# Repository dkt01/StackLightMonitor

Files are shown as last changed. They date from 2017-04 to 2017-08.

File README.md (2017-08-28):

# StackLightMonitor

Documentation Status (https://codedocs.xyz/dkt01/StackLightMonitor/)

[hackaday.io Project Page](https://hackaday.io/project/26995-stack-light-monitor)

[Demo Video](https://youtu.be/2Hm4lpO7gss)
Demo video

Jenkins monitor using industrial stack light as output

## Software Dependencies

The following packages are necessary to run this software:

+ [EtherCard](https://github.com/jcw/ethercard): Driver for ENC28J60 Ethernet controller on Arduino microcontrollers
+ [SparkFun Arduino_Boards](https://github.com/sparkfun/Arduino_Boards): Support for Arduino Pro Micro in Arduino IDE
+ [HTMLMinifier](https://github.com/kangax/html-minifier): HTML and Javascript minifier to reduce html page size.
+ [ImageMagick](http://www.imagemagick.org/script/index.php): Image conversion tool to create favicon.ico file from svg source.

## Attribution

Favicon is a derivative of ["Database" by Tinashe Mugayi](https://thenounproject.com/search/?q=database&creator=1554334&i=955064).  It is covered by the [Creative Commons 3.0 Attribution License](https://creativecommons.org/licenses/by/3.0/us/).

Config page uses CSS from [Pure CSS](https://purecss.io).  It is covered by the [Yahoo! BSD License](https://github.com/yahoo/pure-site/blob/master/LICENSE.md).

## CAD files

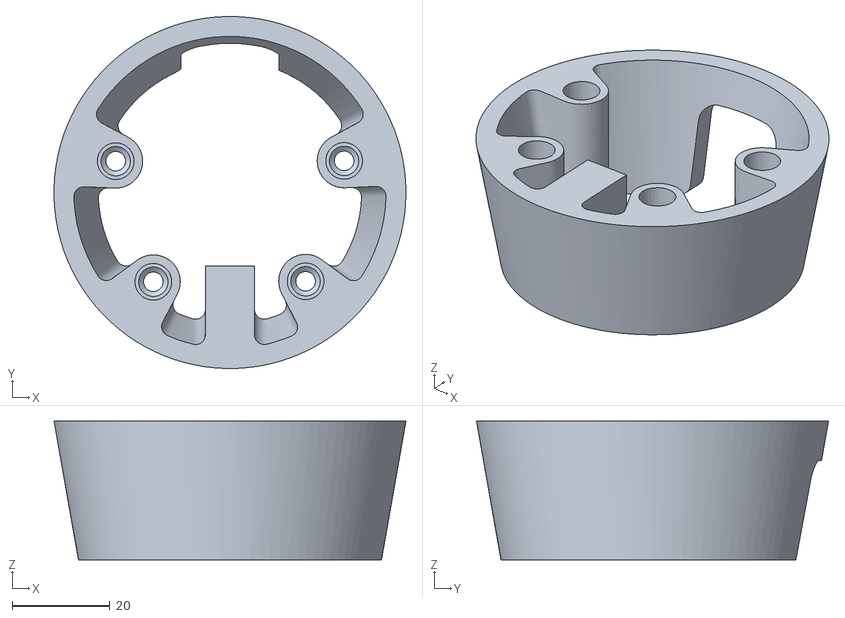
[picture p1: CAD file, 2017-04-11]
CAD/baseBottom.stl
71.8 x 71.9 x 28.3

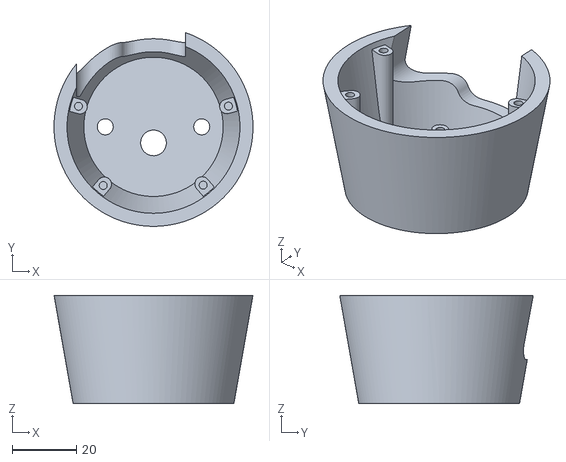
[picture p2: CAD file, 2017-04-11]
CAD/baseTop.stl
61.9 x 60.2 x 33.7

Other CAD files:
CAD/97.ipt
CAD/Arduino Pro Micro Sparkfun.ipt
CAD/ArduinoProMicro.iam
CAD/ElectricalAssembly.iam
CAD/Ethernet.iam
CAD/Ethernet.ipt
CAD/FemaleHeader-01.iam
CAD/FemaleHeader-01.ipt
CAD/FemaleHeader-02.iam
CAD/FemaleHeader-02.ipt
CAD/FemaleHeader.iam
CAD/FemaleHeader.ipt
CAD/FemaleHeader_Single-01.iam
CAD/FemaleHeader_Single-02.iam
CAD/FemaleHeader_Single.iam
CAD/FemalePin-01.ipt
CAD/FemalePin-02.ipt
CAD/FemalePin.ipt
CAD/FullAssembly.iam
CAD/KLDHCX-0202-B_rA2.ipt
CAD/LM317.ipt
CAD/MaleHeader-01.iam
CAD/MaleHeader-01.ipt
CAD/MaleHeader-02.iam
CAD/MaleHeader-02.ipt
CAD/MaleHeader.iam
CAD/MaleHeader.ipt
CAD/PCB.ipt
CAD/Screw Terminal Block 5mm.ipt
CAD/Shield.iam
CAD/TO-92.ipt
CAD/baseBottom.ipt
CAD/baseTop.ipt
CAD/stackLight.iam
CAD/stackLightBase.ipt
CAD/stackLightElement.ipt
CAD/stackLightTop.ipt

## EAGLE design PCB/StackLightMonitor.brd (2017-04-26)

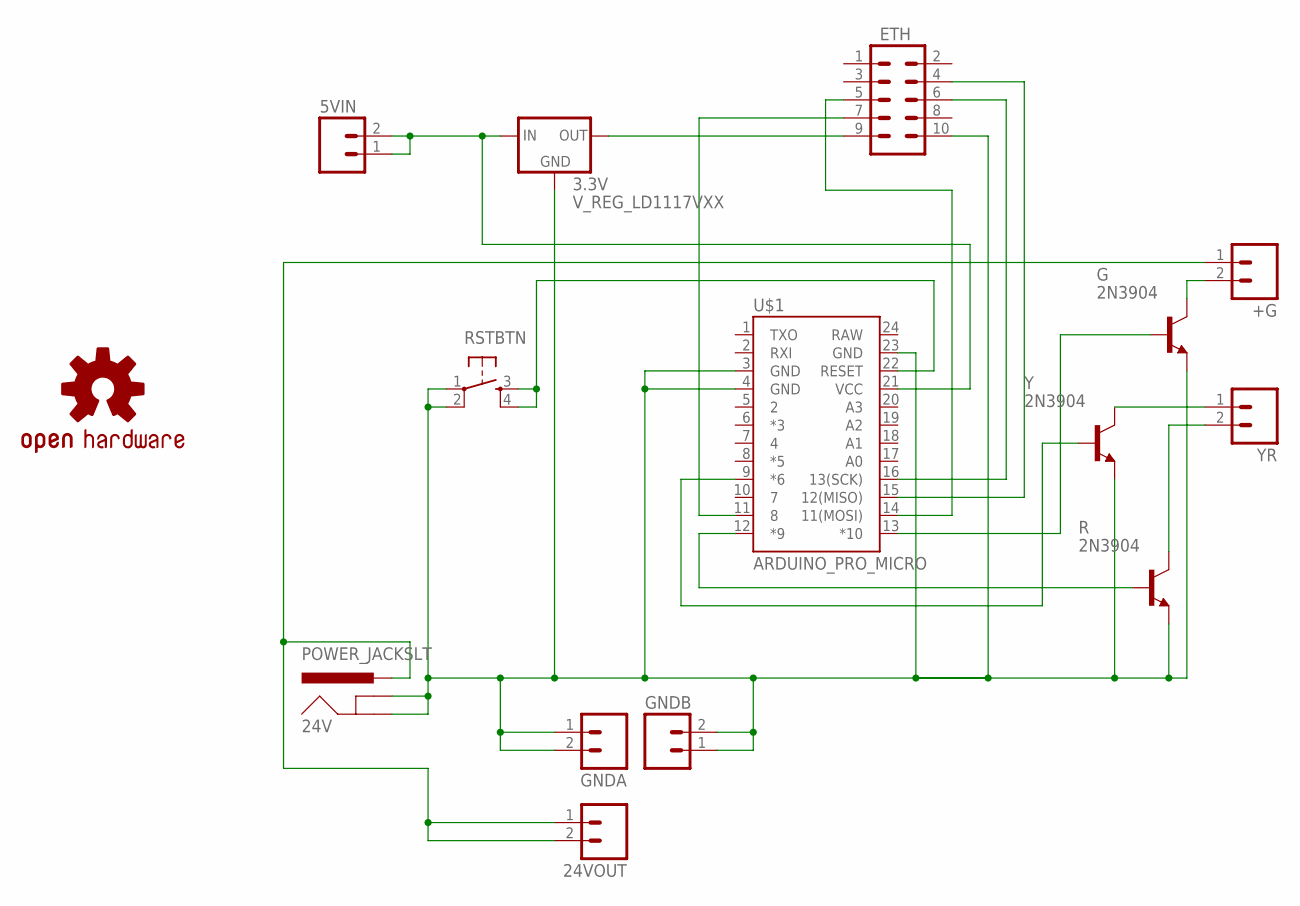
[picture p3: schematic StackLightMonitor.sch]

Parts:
3.3V: V_REG_LD1117VXX; 78XXL
5VIN, 24VOUT: M02PTH; 1X02
24V: POWER_JACKSLT; POWER_JACK_SLOT
+G: M025MM; SCREWTERMINAL-5MM-2
ETH: M05X2PTH; AVR_ICSP
G: 2N3904; TO92
GNDA: M02PTH; 1X02
GNDB: M02PTH; 1X02
LOGO1: OSHW-LOGOL; OSHW-LOGO-L
R: 2N3904; TO92
RSTBTN: TAC_SWITCHPTH; TACTILE-PTH
U$1: ARDUINO_PRO_MICRO
Y: 2N3904; TO92
YR: M025MM; SCREWTERMINAL-5MM-2

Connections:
5V: 3.3V.OUT (IN), 5VIN.1, 5VIN.2, U$1.21 (VCC)
24V: 24V.PWR, 24VOUT.1, 24VOUT.2, +G.1
33V: 3.3V.GND (OUT), ETH.9
CS: ETH.7, U$1.11 (8)
G: G.2 (B), U$1.13 (*10)
GGND: +G.2, G.1 (C)
GND: 3.3V.IN (GND), 24V.GND@1 (GNDBREAK), 24V.GND@2 (GND), ETH.10, G.3 (E), GNDA.1, GNDA.2, GNDB.1, GNDB.2, R.3 (E), RSTBTN.1, RSTBTN.2, U$1.3 (GND), U$1.4 (GND), U$1.23 (GND), Y.3 (E)
MISO: ETH.4, U$1.15 (12(MISO))
MOSI: ETH.5, U$1.14 (11(MOSI))
R: R.2 (B), U$1.12 (*9)
RESET: RSTBTN.3, RSTBTN.4, U$1.22 (RESET)
RGND: R.1 (C), YR.2
SCK: ETH.6, U$1.16 (13(SCK))
Y: U$1.9 (*6), Y.2 (B)
YGND: Y.1 (C), YR.1

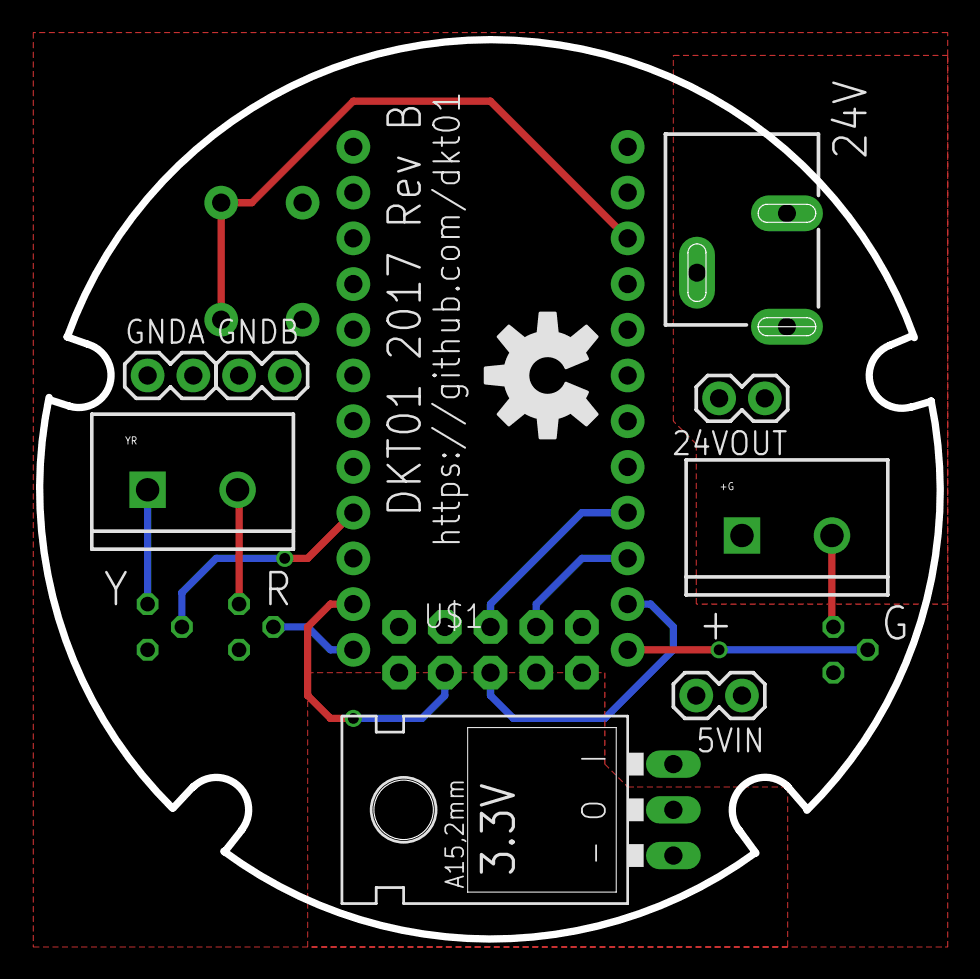
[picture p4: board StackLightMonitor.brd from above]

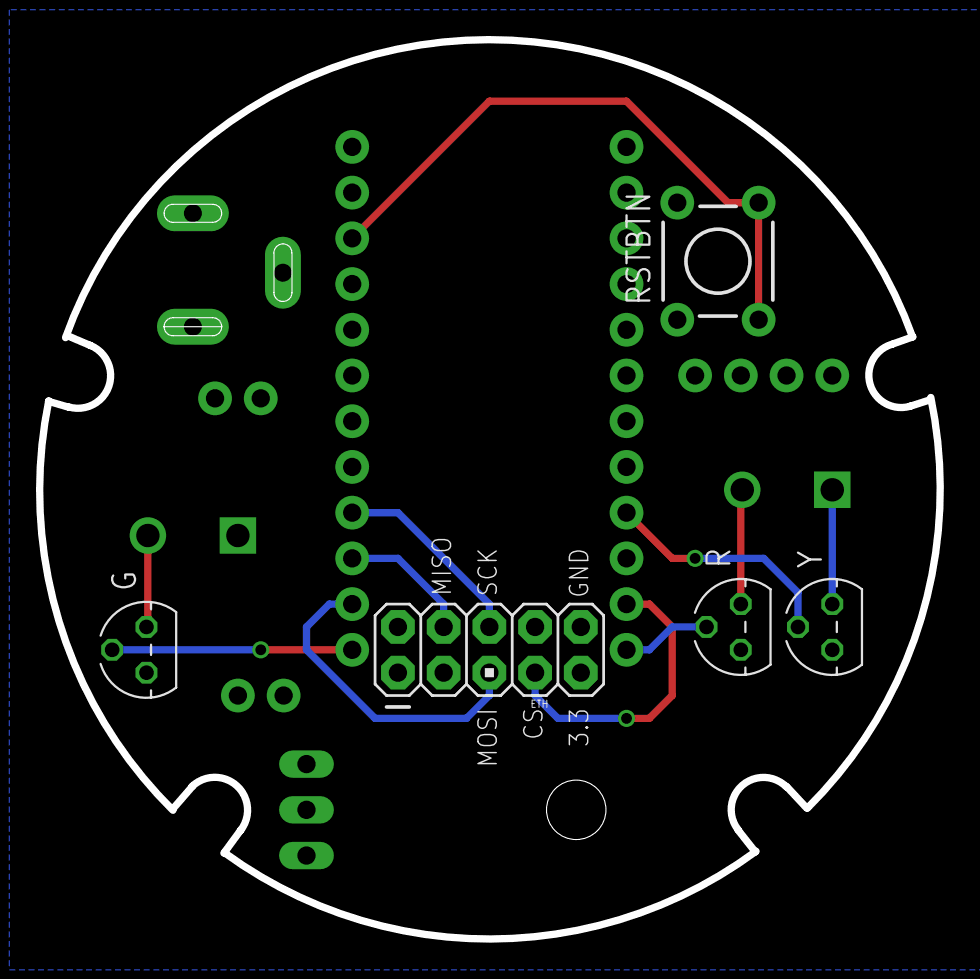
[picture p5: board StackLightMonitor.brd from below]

Board: 2 copper layers, 50.0 x 50.0 mm, 15 parts (5 on the bottom side), 15 nets.

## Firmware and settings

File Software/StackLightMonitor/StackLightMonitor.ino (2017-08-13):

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
#include <EtherCard.h>
#include <IPAddress.h>
#include <EEPROM.h>

#include "StackLight.h"
#include "config_html.h"
#include "favicon_ico.h"

#define DNS_RETRY_INTERVAL_MS 5000
#define SERVER_POLL_INTERVAL_MS 10000

#define STATIC 0  // set to 1 to disable DHCP (adjust myip/gwip values below)
#define BUFFERSIZE 1024

#define HTTP_SERVER_PORT 80 // Port to respond to HTTP config page requests on

#if STATIC
// ethernet interface ip address
static byte myip[] = {
  192,168,1,253 };
// gateway ip address
static byte gwip[] = {
  192,168,1,254 };
#endif

// ethernet mac address - must be unique on your network
static byte mymac[] = { 0x44,0x4b,0x54,0x53,0x4c,0x4d };

byte Ethernet::buffer[BUFFERSIZE]; // tcp/ip send and receive buffer

#define RED    0
#define YELLOW 1
#define GREEN  2
#define NUMCOLORS 3

#define RPIN 9
#define YPIN 6
#define GPIN 10

#define PERSISTENT_MEMORY_VERSION 2
#define PERSISTENT_MEMORY_DOMAIN_ADDRESS 2
#define PERSISTENT_MEMORY_PORT_ADDRESS 4
#define PERSISTENT_MEMORY_ENDPOINT_ADDRESS 6
#define PERSISTENT_MEMORY_DATA_START 8

const uint8_t modulePins[3] = {RPIN, YPIN, GPIN};
StackLight stackLight = StackLight(3, modulePins);

uint8_t buildStatus;

#define BUILDSTATUS_SUCCESS    0x01
#define BUILDSTATUS_UNSTABLE   0x02
#define BUILDSTATUS_FAILURE    0x04
#define BUILDSTATUS_OTHER      0x08
#define BUILDSTATUS_UNKNOWN    0x10
#define BUILDSTATUS_BUILDING   0x80

////////////////////////////////////////////////////////////////////////////////
///////////////////////////// HTTP Response Headers ////////////////////////////
////////////////////////////////////////////////////////////////////////////////

const char http_OK[] PROGMEM =
"HTTP/1.0 200 OK\r\n"
"Content-Type: text/html\r\n"
"Pragma: no-cache\r\n\r\n";

const char http_BadRequest[] PROGMEM =
"HTTP/1.0 400 Bad Request\r\n"
"Content-Type: text/html\r\n\r\n";

const char http_Unauthorized[] PROGMEM =
"HTTP/1.0 401 Unauthorized\r\n"
"Content-Type: text/html\r\n\r\n"
"<h1>401 Unauthorized</h1>";

////////////////////////////////////////////////////////////////////////////////
///////////////////////////// API Query Components /////////////////////////////
////////////////////////////////////////////////////////////////////////////////

const char http_Get_Prefix[] PROGMEM =
"GET ";

const char http_Get_Middle[] PROGMEM =
" HTTP/1.0\r\nHost: ";

const char http_Get_Suffix[] PROGMEM =
"\r\nAccept: text/html\r\n\r\n";


////////////////////////////////////////////////////////////////////////////////
///////////////////////////////// EEPROM Access ////////////////////////////////
////////////////////////////////////////////////////////////////////////////////

uint16_t GetEEPROMWord(uint16_t address)
{
  uint16_t retval = (EEPROM.read(address) & 0xFF);
  retval |= ((EEPROM.read(address + 1) & 0xFF) << 8);
  return retval;
}

void SetEEPROMWord(uint16_t address, uint16_t val)
{
  EEPROM.write(address, val & 0xFF);
  EEPROM.write(address + 1, (val >> 8) & 0xFF);
}

bool HaveURL()
{
  return GetEEPROMWord(PERSISTENT_MEMORY_DOMAIN_ADDRESS) >= PERSISTENT_MEMORY_DATA_START;
}

bool SaveURL(char* urlString)
{
  Serial.println(F("Saving URL..."));

  // Indices within urlString where newline delimiters are
  uint16_t divs[2];

  // Ensure delimiter at end of domain exists and domain string is longer than
  // four characters.  a.co style should be shortest domain.
  divs[0] = strcspn(urlString, "\n");
  if('\n' != urlString[divs[0]]
     || divs[0] < 4)
  {
    Serial.println(F("Could not find first newline"));
    return false;
  }

  // Ensure delimiter at end of port exists
  divs[1] = strcspn(urlString + divs[0] + 1, "\n");
  divs[1] += (divs[0] + 1);
  if('\n' != urlString[divs[1]])
  {
    Serial.println(F("Could not find second newline"));
    Serial.print(F("First newline at "));
    Serial.println(divs[0],DEC);
    Serial.print(F("Second newline at "));
    Serial.println(divs[1],DEC);
    return false;
  }

  // Ensure port string is at least one digit
  if(divs[1] - divs[0] < 2)
  {
    Serial.println(F("Port not present"));
    return false;
  }

  // Ensure an API endpoint string exists
  if('\0' == urlString[divs[1] + 1])
  {
    Serial.println(F("API endpoint not present"));
    return false;
  }

  // Extract and validate port
  uint16_t port = 0;
  uint8_t charVal = 0;
  for(uint16_t i = divs[0] + 1; i < divs[1]; i++)
  {
    // Validate character in range '0'-'9'
    charVal = urlString[i] - 48;
    if(charVal > 9)
    {
      Serial.print(F("Invalid character "));
      Serial.println(charVal, DEC);
      return false;
    }
    // Port is decimal ascii
    port *= 10;
    port += charVal;
    ether.hisport = port;
  }

  // Write pointer to domain string
  uint16_t eepromAddress = PERSISTENT_MEMORY_DATA_START;
  SetEEPROMWord(PERSISTENT_MEMORY_DOMAIN_ADDRESS, PERSISTENT_MEMORY_DATA_START);

  // Write domain string
  for(uint16_t i = 0; i < divs[0]; i++)
  {
    EEPROM.write(eepromAddress, urlString[i]);
    eepromAddress++;
  }
  // Write null stop character
  EEPROM.write(eepromAddress, '\0');
  eepromAddress++;

  // Write pointer to port
  SetEEPROMWord(PERSISTENT_MEMORY_PORT_ADDRESS, eepromAddress);

  // Write port
  SetEEPROMWord(eepromAddress, port);
  eepromAddress += 2;

  // Write pointer to API endpoint URL
  SetEEPROMWord(PERSISTENT_MEMORY_ENDPOINT_ADDRESS, eepromAddress);

  // Write API endpoint URL
  uint16_t i = divs[1] + 1;
  do
  {
    EEPROM.write(eepromAddress, urlString[i]);
    eepromAddress++;
    i++;
  } while(urlString[i] != '\0');
  // Write null stop character
  EEPROM.write(eepromAddress, '\0');

  // Indicate successful write
  return true;
}

uint16_t LoadURL(char* urlString)
{
  Serial.println(F("Loading URL..."));
  uint16_t totalLength = 0;

  // Check that a URL has been written
  if(!HaveURL())
  {
    Serial.println(F("Don't have URL"));
    urlString[0] = '\0';
    return 0;
  }

  // Output full formatted API URL string
  totalLength += LoadDomain(urlString);
  urlString[totalLength] = ':';
  totalLength++;
  totalLength += LoadPort(urlString + totalLength);
  totalLength += LoadEndpoint(urlString + totalLength);

  return totalLength;
}

uint16_t LoadDomain(char* destString)
{
  uint16_t domainSize = 0;
  uint8_t eepromByte = '\0';
  // Get start address for domain string
  uint16_t eepromAddress = GetEEPROMWord(PERSISTENT_MEMORY_DOMAIN_ADDRESS);

  // If start address is invalid, return empty string
  if(!HaveURL())
  {
    destString[0] = '\0';
    return domainSize;
  }

  // Load null-terminated string from EEPROM
  do
  {
    eepromByte = EEPROM.read(eepromAddress);
    destString[domainSize] = eepromByte;
    eepromAddress++;
    domainSize++;
  } while(eepromByte != '\0');

  // Return size not including null stop character
  return domainSize - 1;
}

uint16_t LoadPort()
{
  // Check if URL data is set
  if(!HaveURL())
  {
    return -1;
  }

  uint16_t port = GetEEPROMWord(GetEEPROMWord(PERSISTENT_MEMORY_PORT_ADDRESS));
  SetPort(port);
  return port;
}

uint16_t LoadPort(char* destString)
{
  // Check if URL data is set
  if(!HaveURL())
  {
    return -1;
  }

  uint16_t port = GetEEPROMWord(GetEEPROMWord(PERSISTENT_MEMORY_PORT_ADDRESS));
  return sprintf(destString, "%d", port);
}

uint16_t LoadEndpoint(char* destString)
{
  uint16_t endpointSize = 0;
  uint8_t eepromByte = '\0';
  // Get start address for endpoint string
  uint16_t eepromAddress = GetEEPROMWord(PERSISTENT_MEMORY_ENDPOINT_ADDRESS);

  // If start address is invalid, return empty string
  if(!HaveURL())
  {
    destString[0] = '\0';
    return endpointSize;
  }

  // Load null-terminated string from EEPROM
  do
  {
    eepromByte = EEPROM.read(eepromAddress);
    destString[endpointSize] = eepromByte;
    eepromAddress++;
    endpointSize++;
  } while(eepromByte != '\0');

  // Return size not including null stop character
  return endpointSize - 1;
}


////////////////////////////////////////////////////////////////////////////////
/////////////////////////////// API Query Helpers //////////////////////////////
////////////////////////////////////////////////////////////////////////////////

static uint16_t FillServerQuery(uint8_t sessionID)
{
  // Create API query in payload
  uint8_t* startPos = EtherCard::tcpOffset();
  uint16_t len = sizeof(http_Get_Prefix) - 1;
  memcpy_P(startPos, http_Get_Prefix, len);
  len += LoadEndpoint(startPos+len);
  memcpy_P(startPos + len, http_Get_Middle, sizeof(http_Get_Middle));
  len += sizeof(http_Get_Middle) - 1;
  len += LoadDomain(startPos + len);
  memcpy_P(startPos + len, http_Get_Suffix, sizeof(http_Get_Suffix));
  len += sizeof(http_Get_Suffix) - 1;
  return len;
}

static uint8_t ReceiveServerResponse( uint8_t sessionID,
                                      uint8_t flags,
                                      uint16_t offset,
                                      uint16_t length )
{
  // Reset port to enable http server
  SetPort(HTTP_SERVER_PORT);

  char* responseStart = (char*)(Ethernet::buffer + offset);
  Ethernet::buffer[offset+length] = '\0';
  Serial.println(F("Request callback:"));

  // Serial.println(F("Content:"));
  // Serial.println(responseStart);

  // Find beginning of JSON
  size_t jsonStartIdx = strcspn(responseStart, "{");
  responseStart += jsonStartIdx;
  if(*responseStart != '{')
  {
    Serial.println(F("JSON not found!"));
    return 0;
  }

  char* key = NULL;
  uint8_t keyLen = 0;
  char* value = NULL;
  uint8_t valueLen = 0;

  while(getKVPair(responseStart, key, keyLen, value, valueLen))
  {
    if(keyLen > 0 && valueLen > 0 && 0 == strncmp(key,"building",keyLen))
    {
      if(0 == strncmp(value,"true",valueLen))
      {
        // Set building flag
        buildStatus |= BUILDSTATUS_BUILDING;
        Serial.println(F("Building!"));
      }
      else
      {
        // Clear building flag
        uint8_t statusMask = ~BUILDSTATUS_BUILDING;
        buildStatus &= statusMask;
        Serial.println(F("Not Building!"));
      }
    }
    else if(keyLen > 0 && valueLen > 0 && 0 == strncmp(key,"result",keyLen))
    {
      if(0 == strncmp(value,"\"SUCCESS\"",valueLen))
      {
        // Clear all status flags except success and building
        uint8_t statusMask = BUILDSTATUS_BUILDING | BUILDSTATUS_SUCCESS;
        buildStatus &= statusMask;
        // Set success flag
        buildStatus |= BUILDSTATUS_SUCCESS;
        Serial.println(F("Build: SUCCESS"));
        Serial.print(buildStatus);
      }
      else if(0 == strncmp(value,"\"FAILURE\"",valueLen))
      {
        // Clear all status flags except failure and building
        uint8_t statusMask = BUILDSTATUS_BUILDING | BUILDSTATUS_FAILURE;
        buildStatus &= statusMask;
        // Set failure flag
        buildStatus |= BUILDSTATUS_FAILURE;
        Serial.println(F("Build: FAILURE"));
        Serial.print(buildStatus);
      }
      else if(0 == strncmp(value,"\"NOT_BUILT\"",valueLen))
      {
        // Clear all status flags except other and building
        uint8_t statusMask = BUILDSTATUS_BUILDING | BUILDSTATUS_OTHER;
        buildStatus &= statusMask;
        // Set other flag
        buildStatus |= BUILDSTATUS_OTHER;
        Serial.println(F("Build: NOT_BUILT"));
        Serial.print(buildStatus);
      }
      else if(0 == strncmp(value,"\"ABORTED\"",valueLen))
      {
        // Clear all status flags except other and building
        uint8_t statusMask = BUILDSTATUS_BUILDING | BUILDSTATUS_OTHER;
        buildStatus &= statusMask;
        // Set other flag
        buildStatus |= BUILDSTATUS_OTHER;
        Serial.println(F("Build: ABORTED"));
        Serial.print(buildStatus);
      }
      else if(0 == strncmp(value,"\"UNSTABLE\"",valueLen))
      {
        // Clear all status flags except failure and building
        uint8_t statusMask = BUILDSTATUS_BUILDING | BUILDSTATUS_UNSTABLE;
        buildStatus &= statusMask;
        // Set unstable flag
        buildStatus |= BUILDSTATUS_UNSTABLE;
        Serial.println(F("Build: UNSTABLE"));
        Serial.print(buildStatus);
      }
      else
      {
        // Do nothing and maintain previous status
        Serial.println(F("Build: OTHER"));
        Serial.print(buildStatus);
      }
    }
    responseStart = value + valueLen + 1;
  }
  return 0; // Not used for anything
}

bool getKVPair(char* responseStart, char*& key, uint8_t& keyLen, char*& value, uint8_t& valueLen)
{
  // Every key should start with a double quote and end with a double quote
  size_t findOffset = strcspn(responseStart, "\"");
  if(responseStart[findOffset] != '\"')
  {
    // No key found
    return false;
  }
  // Key is always a string, so don't include the first double quote
  key = responseStart + findOffset + 1;
  responseStart = key;

  findOffset = strcspn(responseStart, "\"");
  if(responseStart[findOffset] != '\"')
  {
    // No key end found
    return false;
  }
  keyLen = findOffset;
  responseStart += findOffset;

  // A colon will always appear immediately before the value
  findOffset = strcspn(responseStart, ":");
  if(responseStart[findOffset] != ':')
  {
    // No KV pair separator found
    return false;
  }
  value = responseStart + findOffset + 1;
  responseStart = value;

  // Comma separates keys, end brace indicates end of selection
  findOffset = strcspn(responseStart, ",}");
  if(responseStart[findOffset] != ',' &&
     responseStart[findOffset] != '}')
  {
    // No value end found
    return false;
  }
  valueLen = findOffset;
  return true;
}

void updatePaterns(StackLight& sl, uint8_t status)
{
  uint8_t illuminateColor = 0;
  // While building, pulse light corresponding to previous build status
  if(status & BUILDSTATUS_BUILDING)
  {
    if(status & BUILDSTATUS_SUCCESS)
    {
      illuminateColor = GREEN;
    }
    else if(status & BUILDSTATUS_FAILURE)
    {
      illuminateColor = RED;
    }
    else
    {
      illuminateColor = YELLOW;
    }
    for(uint8_t i = 0; i < NUMCOLORS; i++)
    {
      if(i == illuminateColor)
      {
        sl.setPattern(i, StackLight::PULSE, 255);
      }
      else
      {
        sl.setPattern(i, StackLight::SOLID, 0);
      }
    }
  }
  else
  {
    // Unknown flash all lights
    if(status & BUILDSTATUS_UNKNOWN)
    {
      for(uint8_t i = 0; i < NUMCOLORS; i++)
      {
        sl.setPattern(i, StackLight::FLASH, 255);
      }
    }
    // Solid corresponding to build status
    else
    {
      if(status & BUILDSTATUS_SUCCESS)
      {
        illuminateColor = GREEN;
      }
      else if(status & BUILDSTATUS_FAILURE)
      {
        illuminateColor = RED;
      }
      else
      {
        illuminateColor = YELLOW;
      }
      for(uint8_t i = 0; i < NUMCOLORS; i++)
      {
        if(i == illuminateColor)
        {
          sl.setPattern(i, StackLight::SOLID, 255);
        }
        else
        {
          sl.setPattern(i, StackLight::SOLID, 0);
        }
      }
    }
  }
}

////////////////////////////////////////////////////////////////////////////////
/// @brief Sets new TCP port for ethercard library.  This is the port used for
///        responses and requests
/// @param newPort New port to listen on/send to
////////////////////////////////////////////////////////////////////////////////
void SetPort(uint16_t newPort)
{
  ether.hisport = newPort;
}


////////////////////////////////////////////////////////////////////////////////
//////////////////////////////// Main Functions ////////////////////////////////
////////////////////////////////////////////////////////////////////////////////
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
void loop()
{
  static bool pendingPut = false;
  bool generalMemCopy = true;

  static bool haveDNS = false;
  static long lastDNSLookup = 0;
  static long lastServerPoll = 0;

  word pos = ether.packetLoop(ether.packetReceive());

  if (pos)
  {
    uint16_t startPoint = 0; // Multi-packet response
    int sz = BUFFERSIZE - pos;
    char* data = (char*) Ethernet::buffer + pos;
    char* sendData = NULL;
    bool complete = false;

    Serial.println(pos);

    ether.httpServerReplyAck();

    if (strncmp("GET / ", data, 6) == 0)
    {
      pendingPut = false;

      Serial.println(F("GET /:"));
      Serial.println(data);
      sendData = const_cast<char*>(config_html);
      if(sizeof(config_html) < sz)
      {
        sz = sizeof(config_html);
      }
      else
      {
        do
        {
          memcpy_P(data, sendData + startPoint, sz); // Copy data from flash to RAM
          ether.httpServerReply_with_flags(sz, TCP_FLAGS_ACK_V);
          startPoint += sz;
          sz = BUFFERSIZE - pos;
          if(sizeof(config_html) - startPoint < sz)
          {
            sz = sizeof(config_html) - startPoint;
            complete = true;
          }
        } while (false == complete);
        sendData += startPoint;
      }
    }
    else if (strncmp("GET /favicon.ico", data, 16) == 0)
    {
      pendingPut = false;

      Serial.println(F("GET /favicon.ico:"));
      Serial.println(data);
      sendData = const_cast<char*>(favicon_ico);
      if(sizeof(favicon_ico) < sz)
      {
        sz = sizeof(favicon_ico);
        complete = true;
      }
      else
      {
        do
        {
          memcpy_P(data, sendData + startPoint, sz); // Copy data from flash to RAM
          ether.httpServerReply_with_flags(sz, TCP_FLAGS_ACK_V);
          startPoint += sz;
          sz = BUFFERSIZE - pos;
          if(sizeof(favicon_ico) - startPoint < sz)
          {
            sz = sizeof(favicon_ico) - startPoint;
            complete = true;
          }
        } while (false == complete);
        sendData += startPoint;
      }
    }
    else if (strncmp("GET /apiURL", data, 10) == 0)
    {
      pendingPut = false;

      Serial.println(F("GET /apiURL:"));
      Serial.println(data);
      generalMemCopy = false; // Doing memcopy here to build response
      sz = sizeof(http_OK);
      memcpy_P(data, http_OK, sz);
      uint16_t urlSize = 0;
      urlSize = LoadURL(data+sz-1); // Start at null character from header string
      sz += (urlSize-1); // Don't send null characters
    }
    else if (strncmp("PUT /apiURL", data, 10) == 0)
    {
      pendingPut = false;

      Serial.println(F("PUT /apiURL:"));
      Serial.println(data);
      char* headerEnd = strstr(data, "\r\n\r\n");
      Serial.print(F("After Header: "));
      Serial.println(headerEnd + 4);
      if(SaveURL(headerEnd + 4))
      {
        sendData = const_cast<char*>(http_OK);
        sz = sizeof(http_OK);
        haveDNS = false;
        Serial.println(F("Pending DNS"));
        stackLight.setPattern(YELLOW,
                              StackLight::PULSE,
                              255,
                              1000);
        stackLight.setPattern(RED,
                              StackLight::SOLID,
                              0);
        stackLight.setPattern(GREEN,
                              StackLight::SOLID,
                              0);
      }
      else if('\0' == *(headerEnd + 4))
      {
        // 2-part put message
        Serial.println(F("Pending PUT"));
        sendData = const_cast<char*>(http_OK);
        sz = sizeof(http_OK);
        pendingPut = true;
      }
      else
      {
        sendData = const_cast<char*>(http_BadRequest);
        sz = sizeof(http_BadRequest);
      }
    }
    else if(true == pendingPut)
    {
      pendingPut = false;

      Serial.println(F("PUT pt2"));
      Serial.println(data);
      if(SaveURL(data))
      {
        sendData = const_cast<char*>(http_OK);
        sz = sizeof(http_OK);
        haveDNS = false;
        Serial.println(F("Pending DNS"));
        stackLight.setPattern(YELLOW,
                              StackLight::PULSE,
                              255,
                              1000);
        stackLight.setPattern(RED,
                              StackLight::SOLID,
                              0);
        stackLight.setPattern(GREEN,
                              StackLight::SOLID,
                              0);
      }
      else
      {
        Serial.println(F("Not PUT pt2!"));
        sendData = const_cast<char*>(http_Unauthorized);
        if(sizeof(http_Unauthorized) < sz)
        {
          sz = sizeof(http_Unauthorized);
        }
      }
    }
    else
    {
      // Page not found
      Serial.println(F("???:"));
      Serial.println(data);
      sendData = const_cast<char*>(http_Unauthorized);
      if(sizeof(http_Unauthorized) < sz)
      {
        sz = sizeof(http_Unauthorized);
      }
    }

    // Send http response
    if(generalMemCopy)
    {
      memcpy_P(data, sendData, sz); // Copy data from flash to RAM
    }
    // ether.httpServerReply(sz-1);
    ether.httpServerReply_with_flags(sz,TCP_FLAGS_ACK_V|TCP_FLAGS_PUSH_V);
    ether.httpServerReply_with_flags(0,TCP_FLAGS_ACK_V|TCP_FLAGS_FIN_V);
    startPoint = 0;
  }

  if( !haveDNS
      && HaveURL()
      && (millis() - lastDNSLookup) > DNS_RETRY_INTERVAL_MS
      && ether.isLinkUp() )
  {
    lastDNSLookup = millis();
    LoadDomain(Ethernet::buffer+60);
    if(!ether.dnsLookup(Ethernet::buffer+60,true))
    {
      Serial.println(F("DNS lookup failed"));
    }
    else
    {
      ether.printIp(F("Server: "), ether.hisip);
      haveDNS = true;
      stackLight.setPattern(GREEN,
                            StackLight::PULSE,
                            255,
                            1000);
      stackLight.setPattern(YELLOW,
                            StackLight::SOLID,
                            0);
      stackLight.setPattern(RED,
                            StackLight::SOLID,
                            0);
    }
  }

  if( haveDNS
      && HaveURL()
      && (millis() - lastServerPoll) > SERVER_POLL_INTERVAL_MS )
  {
    ether.clientTcpReq(ReceiveServerResponse, FillServerQuery, LoadPort());
    updatePaterns(stackLight, buildStatus);
    lastServerPoll = millis();
  }

  // put your main code here, to run repeatedly:
  stackLight.update();
}

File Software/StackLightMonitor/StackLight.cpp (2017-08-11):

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
#include "StackLight.h"

StackLight::StackLight(const uint8_t nModules, const uint8_t* modulePins):
  m_numModules(nModules)
{
  // Allocate dynamic memory
  m_modulePins =       new uint8_t [m_numModules];
  m_modulePatterns =   new Pattern [m_numModules];
  m_moduleBrightness = new uint8_t [m_numModules];
  m_modulePeriods =    new uint16_t [m_numModules];
  m_moduleParams =     new uint8_t [m_numModules];

  // Initialize dynamic memory
  for(uint8_t i = 0; i < m_numModules; i++)
  {
    m_modulePins[i] =       modulePins[i];
    m_modulePatterns[i] =   SOLID;
    m_moduleBrightness[i] = 0;
    m_modulePeriods[i] =    0;
    m_moduleParams[i] =     0;

    // Initialize pin modes
    pinMode(m_modulePins[i], OUTPUT);
    analogWrite(modulePins[i], 64);
  }

  // Populate Gamma correction lookup table
  // Gamma correction for x is:
  // ( x / MAXVAL )^2.5 * MAXVAL
  for(int i = 0; i < 256; i++)
  {
    float x = i;
    x /= 255;
    x = pow(x, 2.5);
    x *= 255;

    GAMMA[i] = x;
  }

  // Start test pattern at initialization
  m_test = -1;
}


StackLight::~StackLight()
{
  // Deallocate dynamic memory
  if(NULL != m_modulePins)
  {
    delete [] m_modulePins;
  }
  if(NULL != m_modulePatterns)
  {
    delete [] m_modulePatterns;
  }
  if(NULL != m_moduleBrightness)
  {
    delete [] m_moduleBrightness;
  }
  if(NULL != m_modulePeriods)
  {
    delete [] m_modulePeriods;
  }
  if(NULL != m_moduleParams)
  {
    delete [] m_moduleParams;
  }
}


void StackLight::update()
{
  m_now = millis();
  // Start test pattern on first update call
  if(m_test == -1)
  {
    m_test = m_now;
  }
  if(m_test > 0)
  {
    // Run test sequence
    SetTest();
  }
  else
  {
    // Run set patterns
    for(uint8_t i = 0; i < m_numModules; i++)
    {
      switch(m_modulePatterns[i])
      {
        case SOLID:
          SetSolid(m_modulePins[i], m_moduleBrightness[i]);
          break;
        case FLASH:
          SetFlash(m_modulePins[i], m_moduleBrightness[i], m_modulePeriods[i]);
          break;
        case PULSE:
          SetPulse(m_modulePins[i], m_moduleBrightness[i], m_modulePeriods[i]);
          break;
        default:
          SetSolid(m_modulePins[i], 0);
      }
    }
  }
}


void StackLight::setPattern(uint8_t moduleNum,
                            Pattern p,
                            uint8_t brightness,
                            uint16_t period,
                            uint8_t param)
{
  if(moduleNum < m_numModules)
  {
    m_modulePatterns[moduleNum]   = p;
    m_moduleBrightness[moduleNum] = brightness;
    m_modulePeriods[moduleNum]    = period;
    m_moduleParams[moduleNum]     = param;
  }
}


void StackLight::setBrightness(uint8_t moduleNum,
                               uint8_t brightness)
{
  if(moduleNum < m_numModules)
  {
    m_moduleBrightness[moduleNum] = brightness;
  }
}


void StackLight::setPeriod(uint8_t moduleNum,
                           uint16_t period)
{
  if(moduleNum < m_numModules)
  {
    m_modulePeriods[moduleNum] = period;
  }
}


void StackLight::setParam(uint8_t moduleNum,
                          uint8_t param)
{
  if(moduleNum < m_numModules)
  {
    m_moduleParams[moduleNum] = param;
  }
}


void StackLight::SetSolid(uint8_t pinNum, uint8_t brightness)
{
  analogWrite(pinNum, GAMMA[brightness]);
}


void StackLight::SetFlash(uint8_t pinNum, uint8_t brightness, uint16_t period)
{
  period /= PERIODDIVISOR;
  unsigned long condensedNow = m_now / PERIODDIVISOR;
  bool invert = (condensedNow % (2 * period)) !=
                (condensedNow % period);

  // Turn on for period ms then off for period ms
  analogWrite(pinNum,
              invert ? GAMMA[0] : GAMMA[brightness]);
}


void StackLight::SetPulse(uint8_t pinNum, uint8_t brightness, uint16_t period)
{
  analogWrite(pinNum,
              GAMMA[CalcPulseBrightness(brightness, period, true)]);
}

void StackLight::SetTest()
{
  // Get time since test sequence started
  unsigned long refTime = m_now - m_test;
  // Total test sequence time is dependent on number of modules.
  // If no modules are active, skip test sequence
  uint16_t maxTime = ( m_numModules > 0 ? (((m_numModules - 1) * (TESTPERIOD)) + (TESTPERIOD * 2))
                                        : 0 );
  if(refTime > maxTime)
  {
    m_test = 0;
  }
  else
  {
    uint8_t sequenceNum = refTime / TESTPERIOD;
    uint16_t phase = (refTime % TESTPERIOD);
    uint8_t curValue = ((float)phase / float(TESTPERIOD)) * 255;

    for(uint8_t i = 0; i < m_numModules; i++)
    {
      if(i == sequenceNum)
      {
        analogWrite(m_modulePins[i], GAMMA[curValue]);
      }
      else if(i == sequenceNum - 1)
      {
        analogWrite(m_modulePins[i], GAMMA[255 - curValue]);
      }
      else
      {
        analogWrite(m_modulePins[i], 0);
      }
    }
  }
}


uint8_t StackLight::CalcPulseBrightness(uint8_t brightness, uint16_t period, bool smooth,
                                        uint8_t offBrightness, uint16_t offset)
{
  bool invert = false;
  period /= PERIODDIVISOR;
  offset /= PERIODDIVISOR;
  unsigned long condensedNow = m_now / PERIODDIVISOR;
  if(smooth)
  {
    invert = ((condensedNow + offset) % (2 * period)) !=
             ((condensedNow + offset) % period);
  }
  uint16_t curPhase = ((condensedNow + offset) % period);
  if(invert)
  {
    curPhase = period - curPhase;
  }
  uint8_t brightnessRange = brightness - offBrightness;
  uint32_t outBrightness = curPhase * brightnessRange;
  outBrightness /= period;
  outBrightness += offBrightness;
  if(outBrightness > brightness)
  {
    outBrightness = brightness;
  }
  return static_cast<uint8_t>(outBrightness);
}

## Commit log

2017-04-09 Added PCB files
    [StackLightMonitor.brd, StackLightMonitor.sch]
2017-04-09 Added some CAD files
    [97.ipt, Arduino Pro Micro Sparkfun.ipt, ArduinoProMicro.iam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]
2017-04-10 Possibly complete CAD
    [ElectricalAssembly.iam, FullAssembly.iam, PCB.ipt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]
2017-04-11 Updated CAD for 3D printing. Fixed some constraints that were broken
    [ElectricalAssembly.iam, FullAssembly.iam, Shield.iam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]
2017-04-26 Updated silkscreen
    [StackLightMonitor.brd]
2017-05-03 Updates to config webpage
    + Removed fetch api to support older browsers
    + No longer require CORS support from API servers
    + Some style changes
    + Job endpoint validation to support sending good address to Arduino
2017-05-06 Added favicon support and fixed apiURL request endpoint address
    [StackLightMonitor.ino]
2017-05-07 Made favicon transparent background Added apiURL save and load functions Fixed webpage onload function to actually do something
    [StackLightMonitor.ino]
2017-05-16 Fixed config PUT request handling
    [StackLightMonitor.ino]
2017-05-25 Sending API queries to Jenkins, but only printing returned value
2017-06-11 Fixed support for multi-packet PUT requests
    [StackLightMonitor.ino]
2017-08-13 Fixed bug where HTTP server changed port to the port of the Jenkins server.
    [StackLightMonitor.ino]

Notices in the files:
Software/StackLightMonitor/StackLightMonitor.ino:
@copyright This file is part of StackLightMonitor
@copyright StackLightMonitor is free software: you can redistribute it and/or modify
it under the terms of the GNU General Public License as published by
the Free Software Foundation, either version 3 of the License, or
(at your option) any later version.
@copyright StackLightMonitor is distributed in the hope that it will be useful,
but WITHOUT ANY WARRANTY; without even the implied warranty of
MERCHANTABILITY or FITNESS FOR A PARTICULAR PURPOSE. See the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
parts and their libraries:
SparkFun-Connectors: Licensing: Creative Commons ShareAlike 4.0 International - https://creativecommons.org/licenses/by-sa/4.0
